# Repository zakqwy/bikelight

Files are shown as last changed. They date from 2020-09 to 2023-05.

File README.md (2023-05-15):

## bikelight
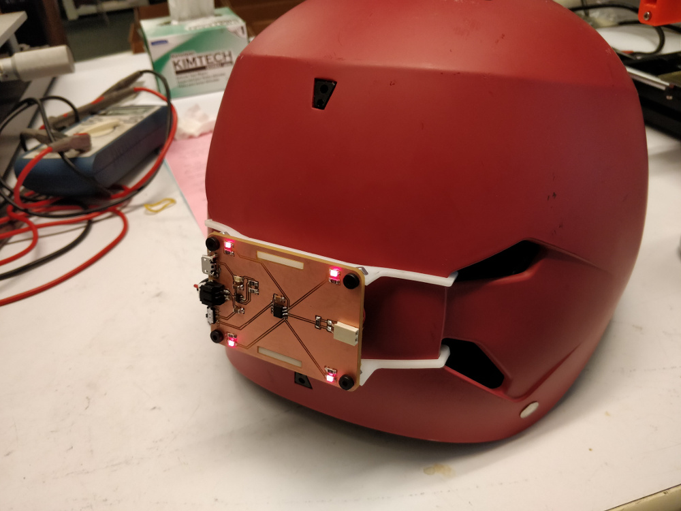
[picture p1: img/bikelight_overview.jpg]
bikelight_overview


It's a blinky red light for the back of my bike helmet.

bikelight

The circuit uses an ATtiny412 to control four red LEDs, along with a Microchip MCP73831 lipo charge controller for battery management and a micro-USB jack for charging.

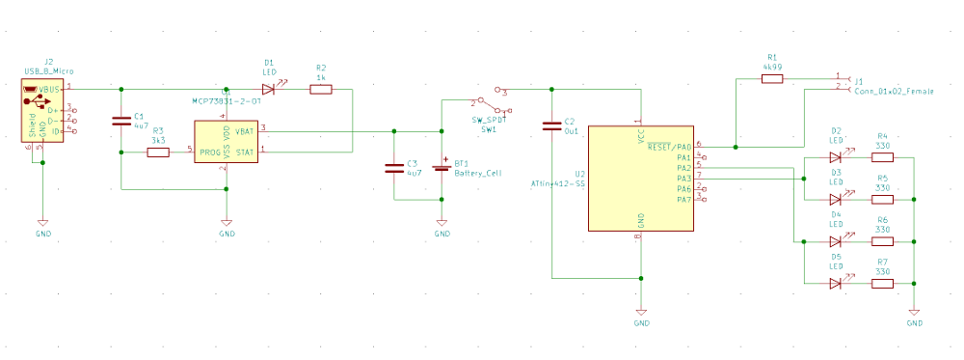
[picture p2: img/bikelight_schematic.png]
bikelight_schematic


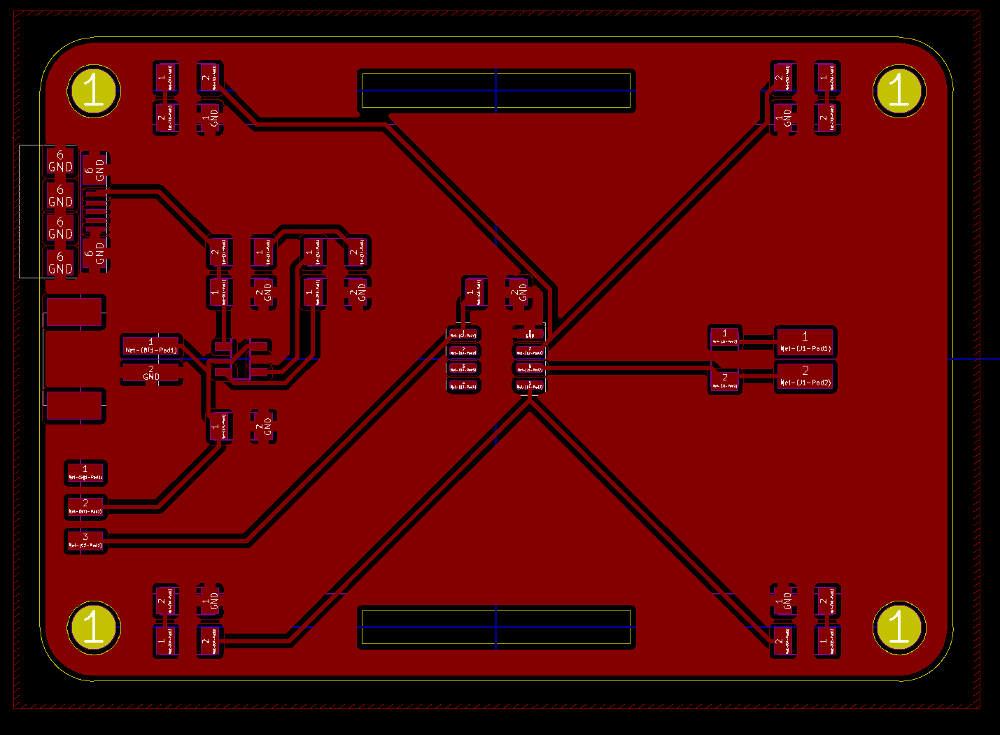
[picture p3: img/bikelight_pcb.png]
bikelight_pcb


The circuit is designed to be milled on a single sided chunk of FR1 using a 1/64" end mill. If you use [mods](mods.cba.mit.edu), the three layer *.svg files (holes, outline, and traces) are in the /pcb directory. After assembling and programming with [pyupdi](https://github.com/mraardvark/pyupdi) and an FTDI cable, I masked off the USB jack and slide switch and sprayed it with a few coats of clear varnish.

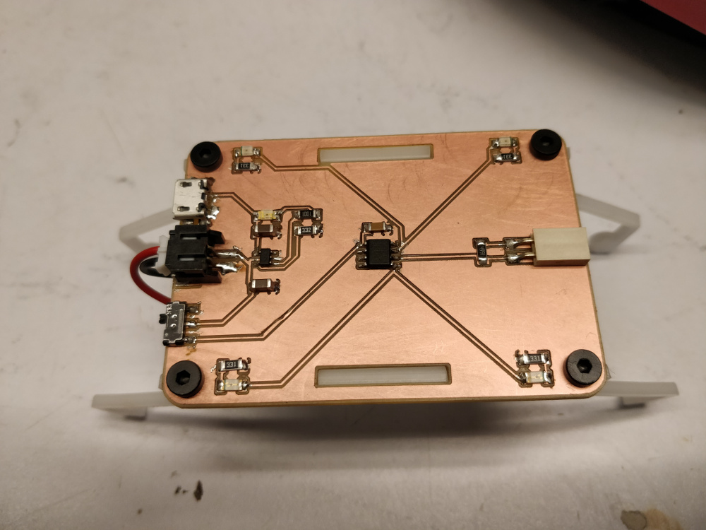
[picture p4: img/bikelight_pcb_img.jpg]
bikelight_pcb_img


The pcb attaches using M3 hardware to two laser cut acetal clips, which then snap into [my helmet](https://www.bernhelmets.com/collections/bike/products/summer-watts?variant=13190223200315). If you have the same model, this will probably work for you too, otherwise you'll need to figure something else out. Laser cut files for these parts are in the /cad directory, intended to be cut from 2.5 mm acetal.

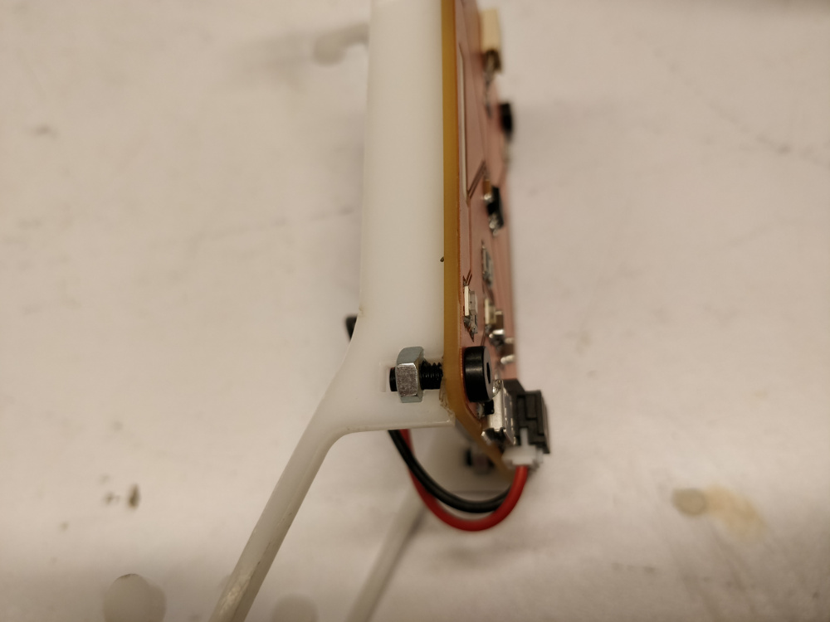
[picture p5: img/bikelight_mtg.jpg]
bikelight_mtg


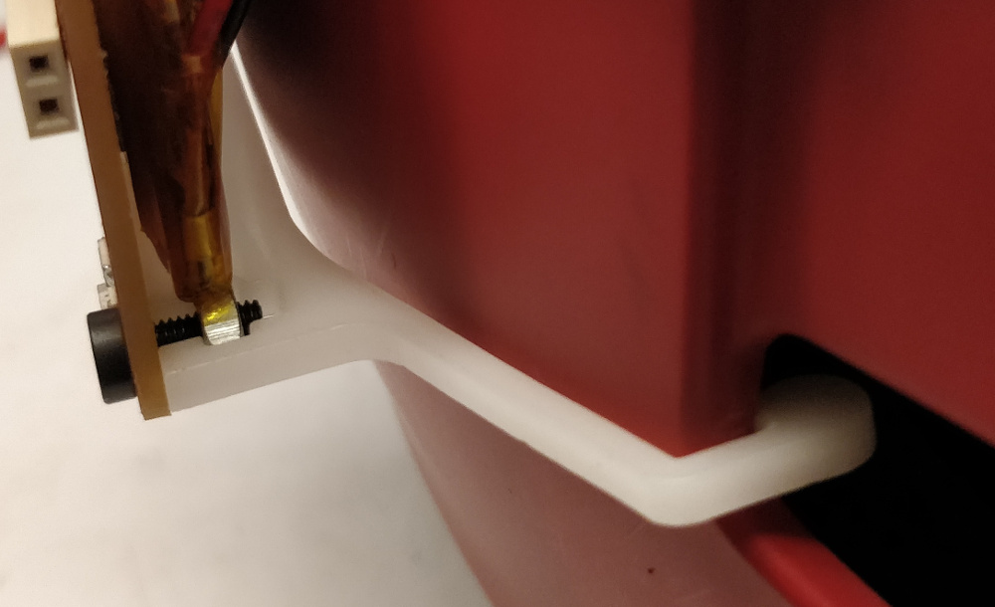
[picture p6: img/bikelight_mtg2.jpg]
bikelight_mtg2


I used a 1200 mAH lipo battery since we had a few on hand; it's secured to the rear of the pcb using VHB tape. I snagged a JST PH off a spare Feather, but if you plan ahead you can buy the part [here](https://www.adafruit.com/product/1769). Note that lipo batteries are inherently dangerous, so don't build this circuit unless you're familiar with their quirks (and make sure to use one with a built-in protection circuit). Yes, if my helmet ever actually has to do its job, my head will likely catch fire.

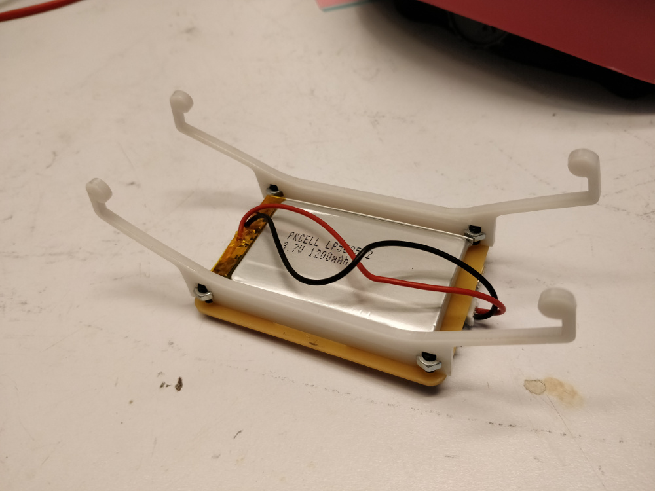
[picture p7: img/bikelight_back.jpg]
bikelight_back


bikelight! blink blink blink blink blink

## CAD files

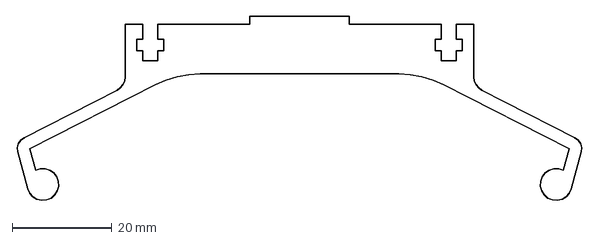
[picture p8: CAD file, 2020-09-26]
cad/bikelight_acetal_frame.dxf
113.7 x 37.1 mm

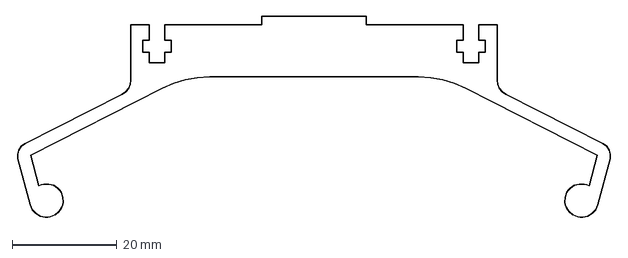
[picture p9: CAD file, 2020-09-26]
cad/bikelight_acetal_frame_top.dxf
113.7 x 38.5 mm

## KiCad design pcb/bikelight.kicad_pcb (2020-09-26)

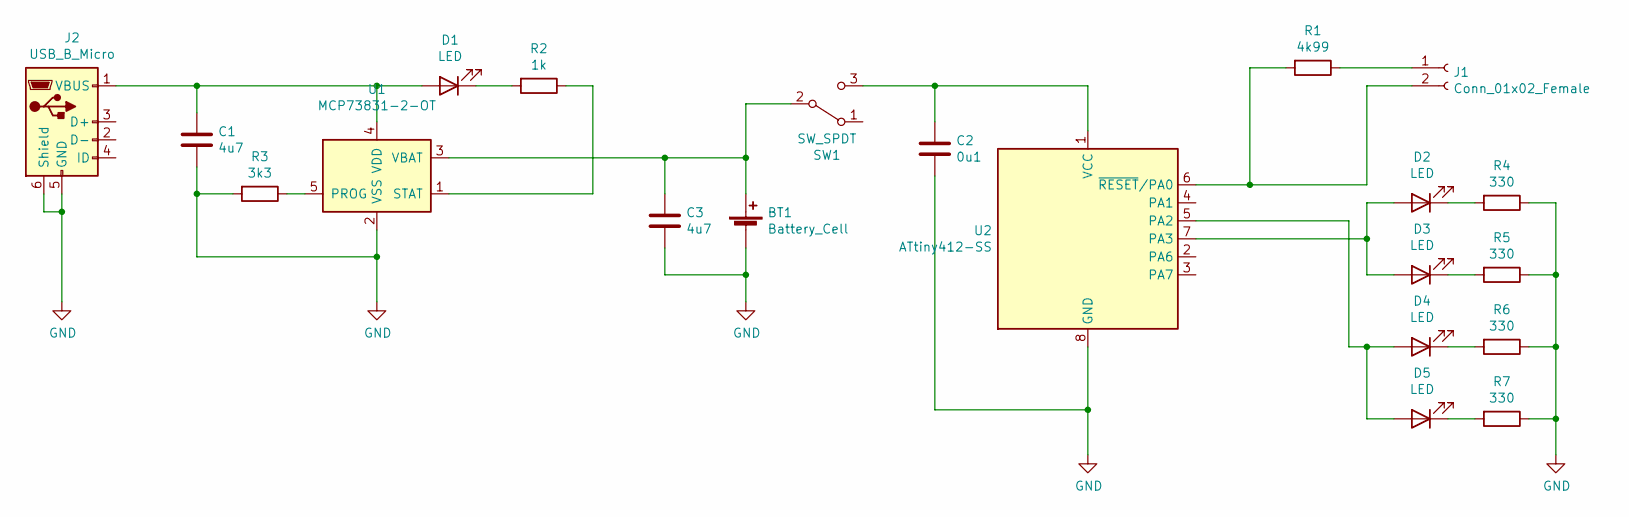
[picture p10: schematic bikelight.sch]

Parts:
BT1: Battery_Cell; JST_PH_S2B-PH-K_1x02_P2.00mm_Horizontal_fab
C1, C3: 4u7; fab-C1206FAB
C2: 0u1; fab-C1206FAB
D1, D2, D3, D4, D5: LED; fab-LED1206FAB
J1: Conn_01x02_Female; CONN_UPDI_2PIN
J2: USB_B_Micro; fab-USB_MICRO
R1: 4k99; fab-R1206FAB
R2: 1k; fab-R1206FAB
R3: 3k3; fab-R1206FAB
R4, R5, R6, R7: 330; fab-R1206FAB
SW1: SW_SPDT; fab-SPDTSWITCH
U1: MCP73831-2-OT; fab-SOT23-5
U2: ATtiny412-SS; SOIC-8_3.9x4.9mm_P1.27mm

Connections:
GND: BT1.2 (-), C1.2, C2.2, C3.2, J2.5 (GND), J2.6 (Shield), R3.2, R4.1, R5.1, R6.1, R7.1, U1.2 (VSS), U2.8 (GND)
unnamed: BT1.1 (+), C3.1, SW1.2 (B), U1.3 (VBAT)
unnamed: C1.1, D1.2 (A), J2.1 (VBUS), U1.4 (VDD)
unnamed: C2.1, SW1.3 (C), U2.1 (VCC)
unnamed: D1.1 (K), R2.2
unnamed: D2.1 (K), R4.2
unnamed: D2.2 (A), D3.2 (A), U2.7 (PA3)
unnamed: D3.1 (K), R5.2
unnamed: D4.1 (K), R6.2
unnamed: D4.2 (A), D5.2 (A), U2.5 (PA2)
unnamed: D5.1 (K), R7.2
unnamed: J1.1, R1.1
unnamed: J1.2, R1.2, U2.6 (~RESET~/PA0)
unnamed: R2.1, U1.1 (STAT)
unnamed: R3.1, U1.5 (PROG)

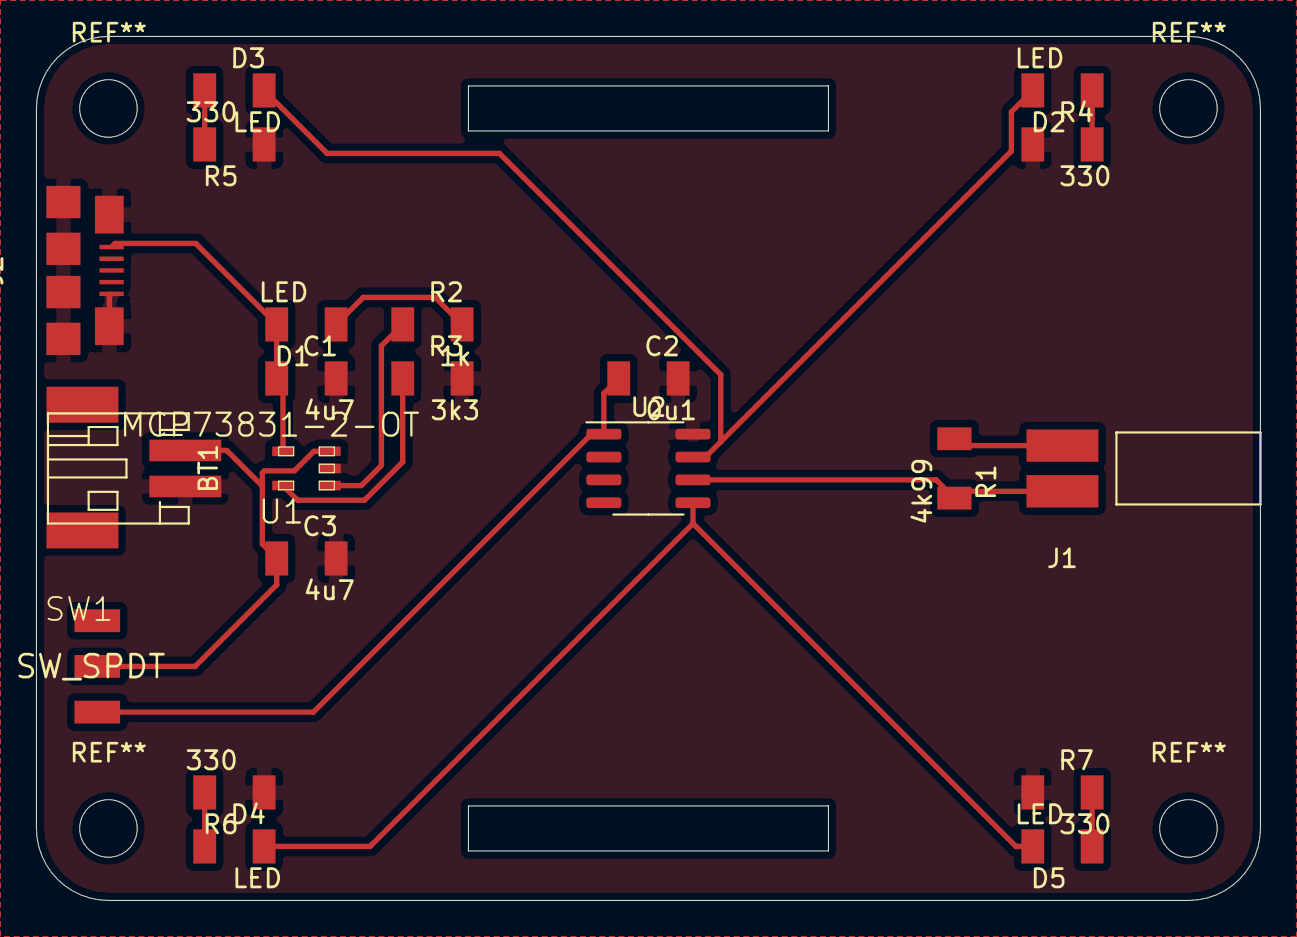
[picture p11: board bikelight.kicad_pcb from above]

Board: 2 copper layers, 68.0 x 48.0 mm, 21 parts (0 on the bottom side), 15 nets.

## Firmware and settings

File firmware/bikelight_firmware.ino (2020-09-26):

#include <avr/io.h>

#define LED_TOP PIN3_bm
#define LED_BOTTOM PIN2_bm

void setup() {
    // GPIO setup
    PORTA.DIRSET = LED_TOP;
    PORTA.DIRSET = LED_BOTTOM;
}

void loop() {
    PORTA.OUTCLR = LED_TOP;
    PORTA.OUTSET = LED_BOTTOM;
    delay(100);
    PORTA.OUTSET = LED_TOP;
    PORTA.OUTCLR = LED_BOTTOM;
    delay(100);
}
